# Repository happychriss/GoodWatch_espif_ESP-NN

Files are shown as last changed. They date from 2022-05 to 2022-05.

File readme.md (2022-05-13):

##### GoodWatch - a SuperSmart eInk ML Learning driven AlarmClock
## This version is using Arduino as a *Component* and allows ESP menuconfig adjustment

* using ML (Edge Impulse) Speech Recognition to set-up the Alarm
* using a guesture sensor for wake-up
* dimmable ePaper FrontLight for readability at night with a super soft dimm
* MP3 via SPIFF to play multiple wake-up sounds (moved now to SPIFF)
* ESP 32 Wemos Pro for programming
* power saving - runtime minimum 3 month on battery
* boot speed optimized with menuconfig
* PCB Board included
## Read more at: 
https://44-2.de/goodwatch-eink-alarm-clock-with-voice-recognition/

You will also find more information on the ESP32 programming using EdgeImpulse ML and transfer learning.

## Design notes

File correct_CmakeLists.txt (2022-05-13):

cmake_minimum_required(VERSION 3.16.0)
include($ENV{IDF_PATH}/tools/cmake/project.cmake)
list(APPEND EXTRA_COMPONENT_DIRS arduino)
project(GoodWatch_espif)

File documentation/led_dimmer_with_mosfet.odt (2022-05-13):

LED Dimming 21 V with MOSFET

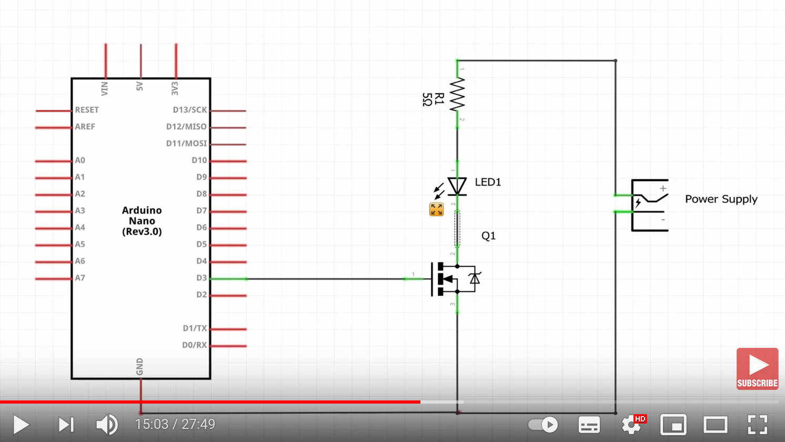
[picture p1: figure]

Type

IRF3708 (TO-220) http://s.click.aliexpress.com/e/_sUN3um

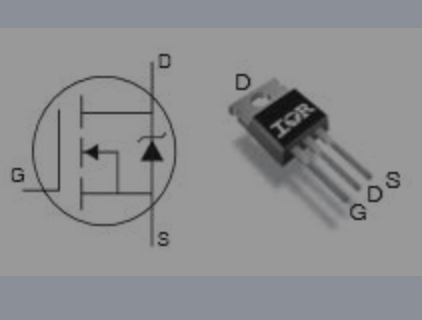
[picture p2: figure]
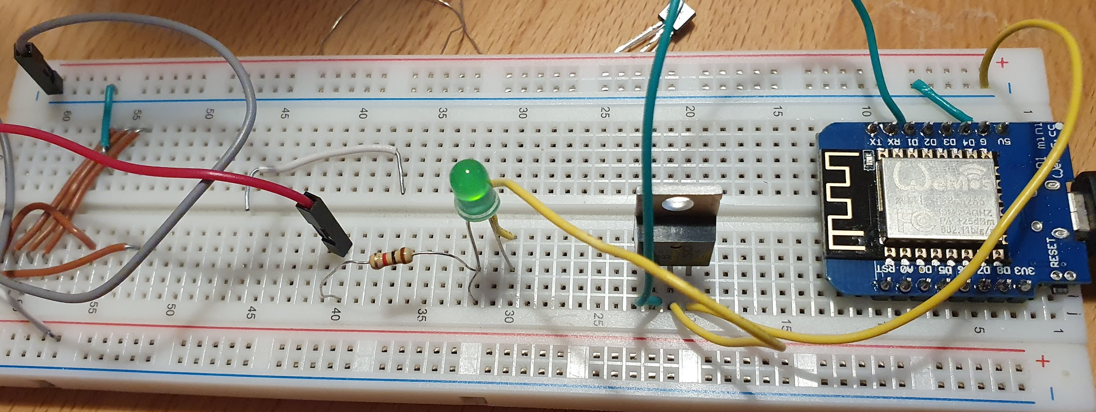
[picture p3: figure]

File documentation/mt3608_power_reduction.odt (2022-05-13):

Power Consumption of MT

https://hackaday.com/2019/01/27/reworking-mt3608-boost-converters-for-lower-idle-current-draw/

Idle poser consumption is above 1ma.

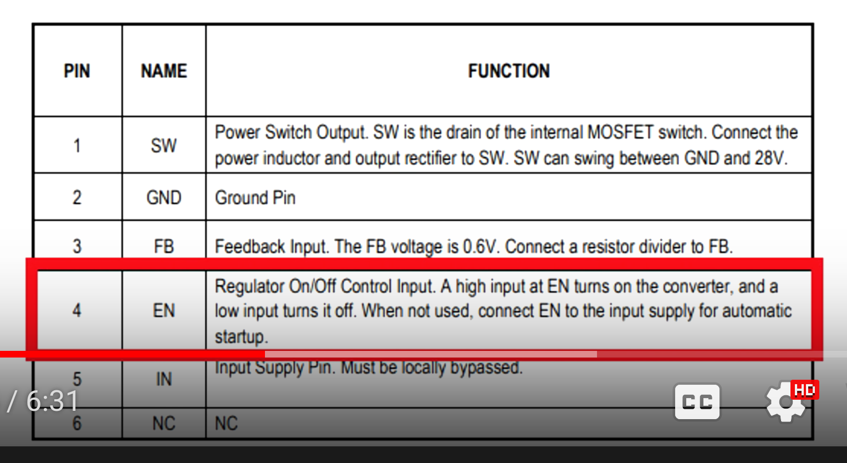
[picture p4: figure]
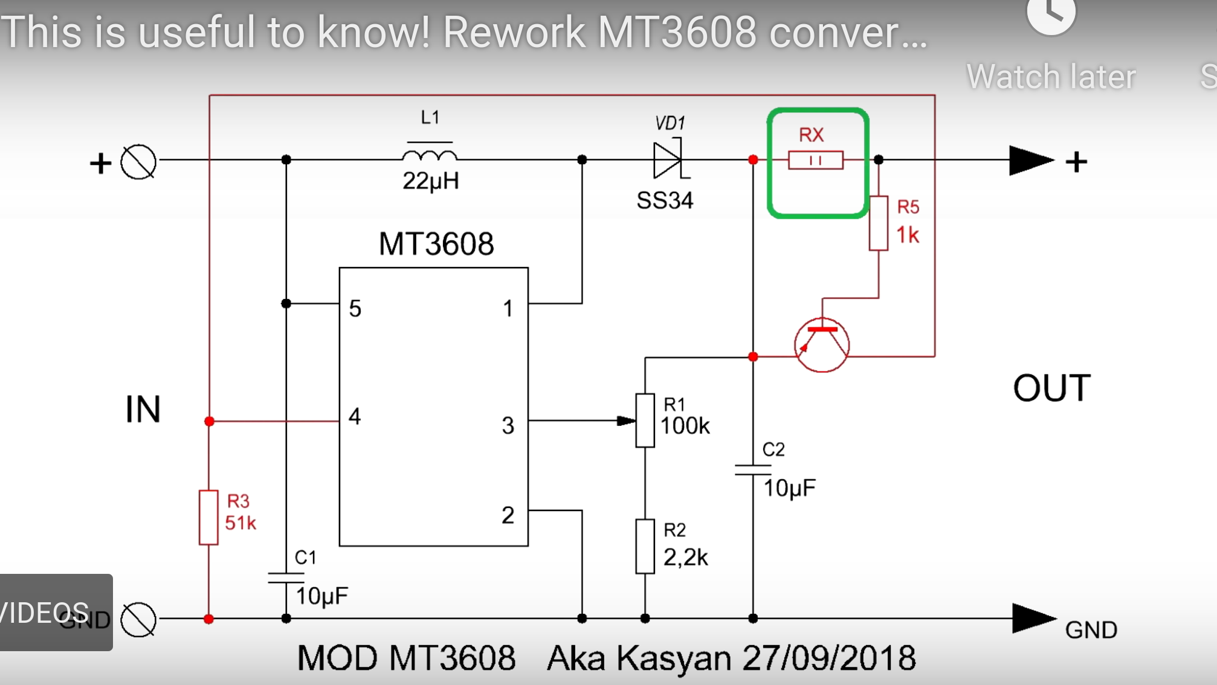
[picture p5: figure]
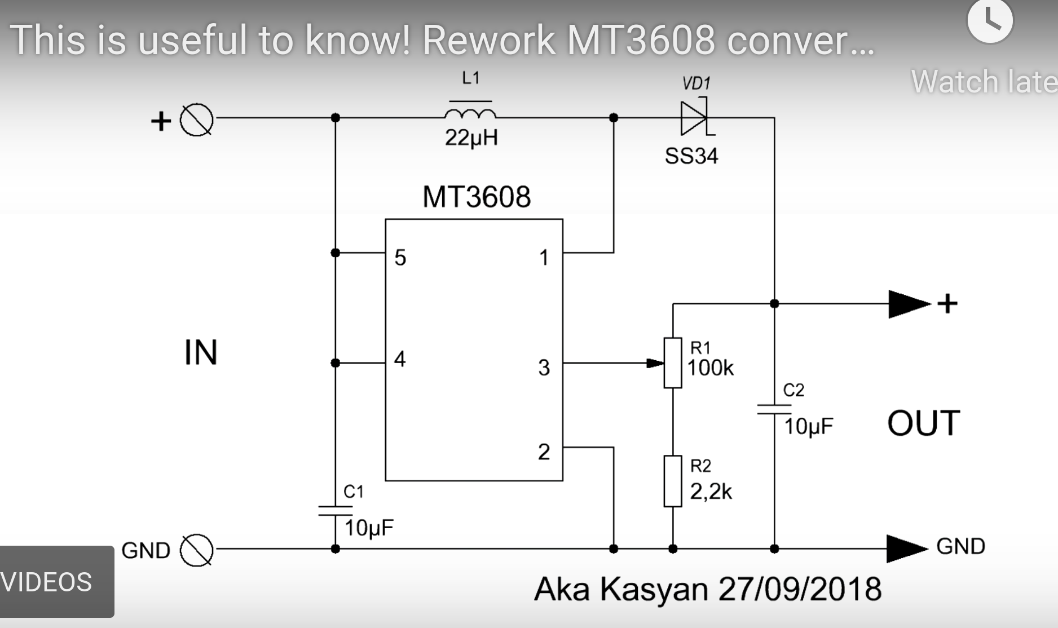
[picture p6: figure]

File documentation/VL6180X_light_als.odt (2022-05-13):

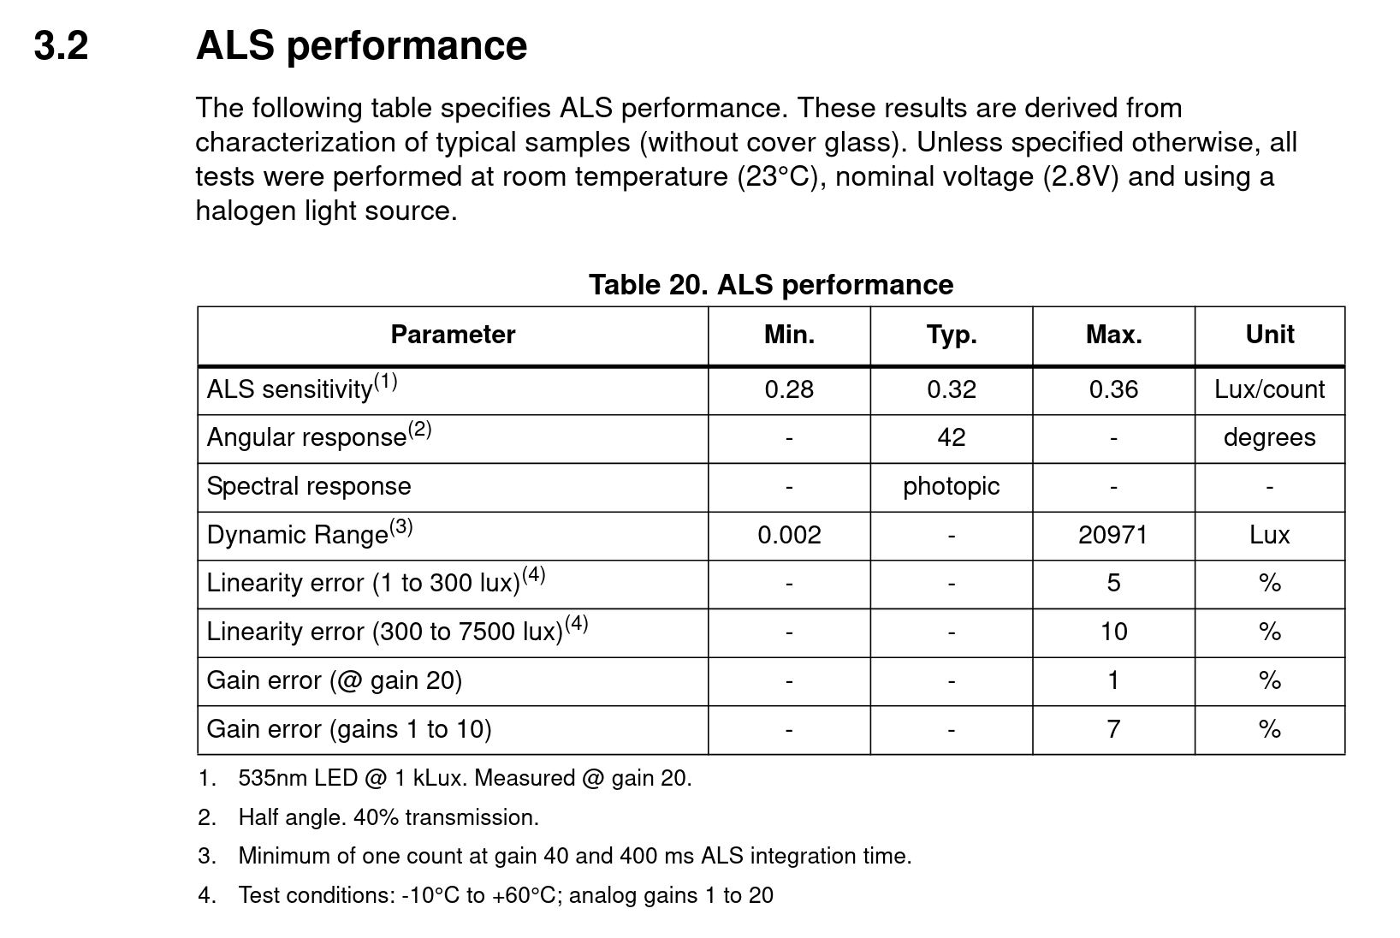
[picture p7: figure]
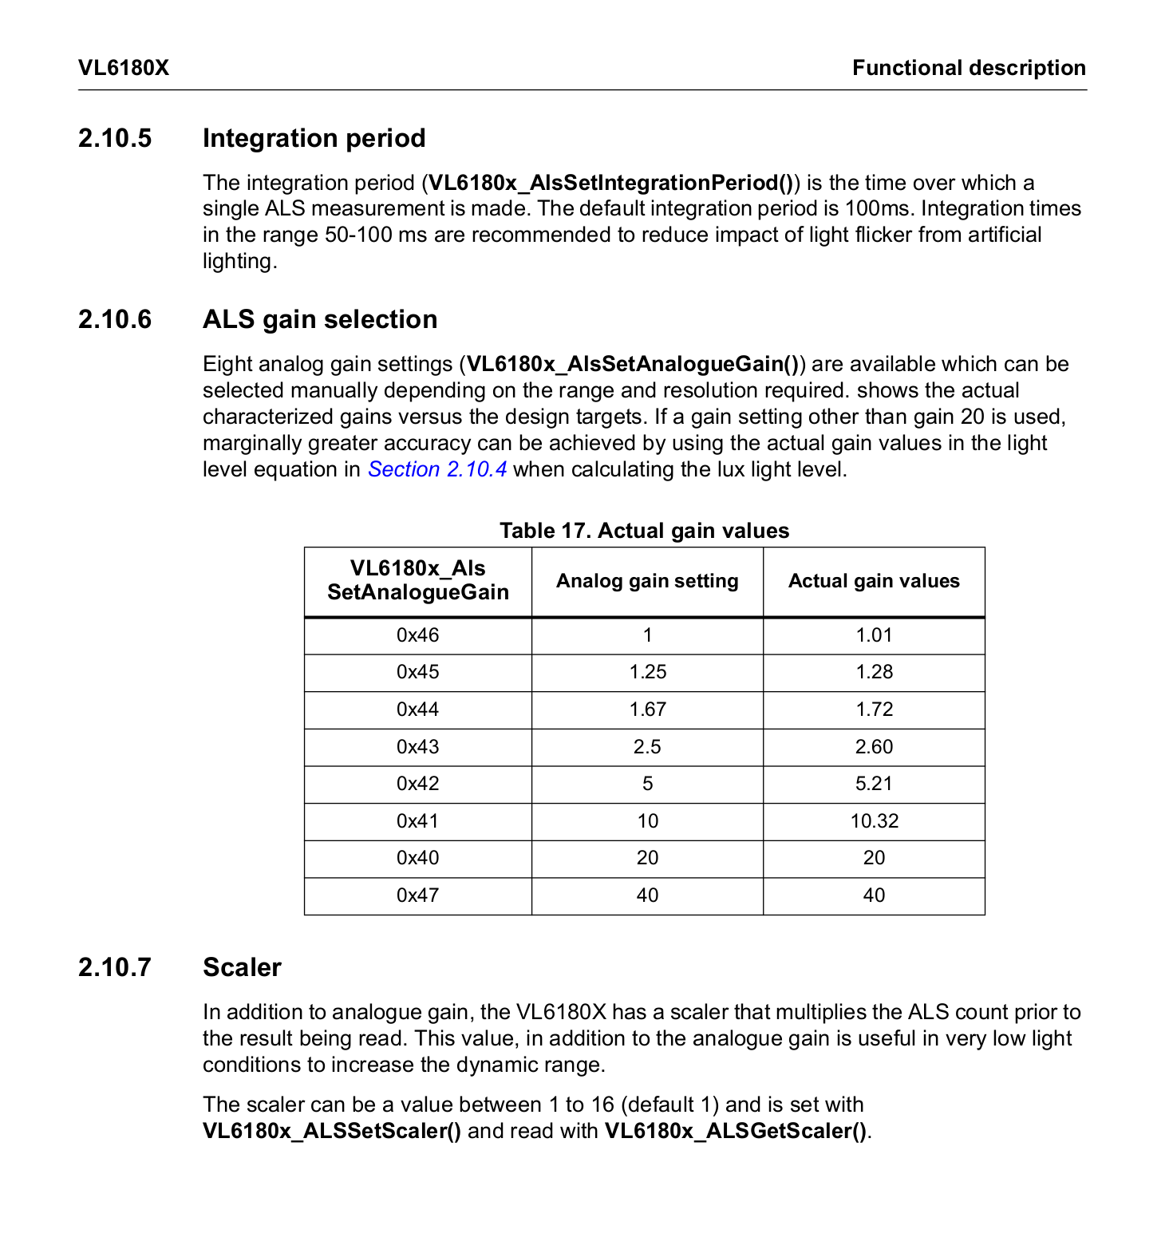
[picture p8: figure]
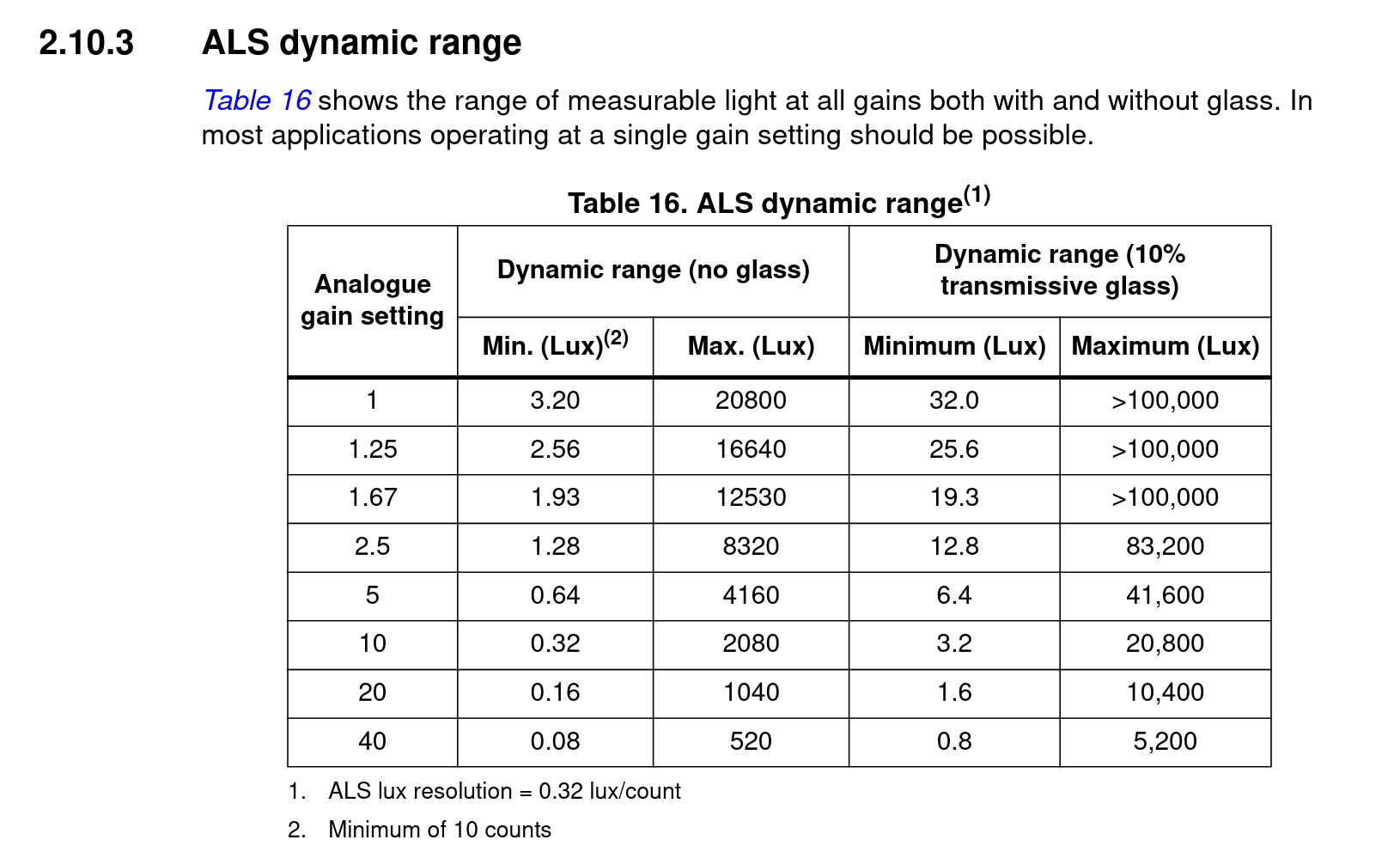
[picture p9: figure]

ALS

0.002 Lux

one count

ALS Analogue Gain: 0x47 = gain 40: SYSALS__ANALOGUE_GAIN = 7, address: 0x03F

ALS Integration Time: 400MS: SYSALS__INTEGRATION_PERIOD, Address: 0x040 = 0x18F (8.bit gesetzt)

ALS Scaler =16, FIRMWARE__RESULT_SCALER 0x7, address 0x120

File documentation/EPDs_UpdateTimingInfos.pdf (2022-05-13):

List of my e-paper displays and their update times and behavior

size | | | panel | controller | full update | | | | comment
inches | depth | pixel | | | time sec | time sec | to buffer | to screen
1,54 | b/w | 200x200 | GDEP015OC1 | IL3829 | 1,2 | 0,3 | √ | √
1,54 | 3-color | 200x200 | GDEW0154Z04 | IL0376F | 7,2 | 7,2 | - | - | controller has no window part addressing
2,13 | b/w | 128x250 | GDE0213B1 | IL3895 | 3,9 | 0,3 | √ | √ | phased out
2,13 | b/w | 128x250 | GDEH0213B72 | IL3897 | 1,7 | 0,2 | √ | √ | new replacement
2,13 | b/w | 128x250 | GDEH0213B73 | SSD1675B | 3,8 | 0,2 | √ | √ | newer replacement
2,13 | 3-color | 104x212 | GDEW0213Z16 | IL0373 | 15 | 15 | √ | √ | screen boarder flashes also
2.13 | b/w | 104x212 | GDEW0213I5F | IL0373 | 2,1 | 0,3 | √ | √ | flexible display
2,6 | b/w | 152x296 | GDEW026T0 | IL0373 | 1,6 | 1,3 | √ | √
2,7 | b/w | 176x264 | GDEW027W3 | IL91874 | 2 | 0,4 | √ | √ | with wavetable from new demo source
2,7 | 3-color | 176x264 | GDEW027C44 | IL91874 | 16 | 16 | √ | √ | leaves visible boarder of partial window
2,9 | b/w | 128x296 | GDEH029A1 | IL3820 | 1,6 | 0,42 | √ | √
2,9 | b/w | 128x296 | GDEW029T5 | IL0373 | 2,1 | 0,4 | √ | √
2,9 | 3-color | 128x296 | GDEW029Z10 | IL0373 | 15 | 15 | √ | √ | screen boarder flashes also
3,7 | b/w | 240x416 | GDEW0371W7 | IL0324 | 3 | 1,5 | √ | √ | charge balancing waveform table for differential update
4,2 | b/w | 400x300 | GDEW042T2 | IL0398 | 1,6 | 0,6 | √ | √ | new waveform table for differential update
4,2 | 3-color | 400x300 | GDEW042Z15 | IL0398 | 16 | 16 | √ | - | refresh to partial screen would modify the other half screen
5,83 | b/w | 600x448 | GDEW0583T7 | IL0371 | 15 | 15 | √ | - | controller provides no differential update
7,5 | b/w | 640x384 | GDEW075T8 | IL0371 | 4,3 | 4,3 | √ | - | controller provides no differential update
7,5 | b/w | 800x480 | GDEW075T7 | GD7965 | 4,2 | 1,6 | √ | √ | charge balancing waveform table for differential update
7,5 | 3-color | 640x384 | GDEW075Z09 | IL0371 | 32 | 32 | √ | - | controller provides no differential update
7,5 | 3-color | 800x480 | GDEW075Z08 | GD7965 | 17 | 17 | √ | (√) | 3-color allows no differential update

times are "busy active" times after refresh command sent to controller
"-" partial update to screen: whole screen updates (and flashes)
(√) partial update can be disabled in GxEPD2 (usePartialUpdate = false) for better image

4.2" b/w: new waveform table for differential update, compromise between ghosting and persistence

resolution | partial update

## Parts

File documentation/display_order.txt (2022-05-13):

1x8pin header right angle female single row socket connector 2.54mm pitch

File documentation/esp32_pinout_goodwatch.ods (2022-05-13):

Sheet: GoodWatch
GPIO | Input | Output |  | Notes
0 | pulled up |  | DC PIN | outputs PWM signal at boot
1 | TX Pin |  |  | debug output at boot
2 | OK |  | RESET | connected to on-board LED
3 | OK |  | RX Pin | HIGH at boot
4 | OK | OK | I2S-WS/LRCK | I2S Microphone
5 | OK | OK | SS/CS | outputs PWM signal at boot
6 | X | X |  | connected to the integrated SPI flash
7 | X | X |  | connected to the integrated SPI flash
8 | X | X |  | connected to the integrated SPI flash connected to the integrated SPI flash
9 | X | X |  | connected to the integrated SPI flash
10 | X | X |  | connected to the integrated SPI flash
11 | X | X |  | connected to the integrated SPI flash
12 | OK | OK | OK | POWER Controll (switch off other devices on sleep)
13 | OK | OK | OK
14 | OK | OK | OK | outputs PWM signal at boot
15 | OK | OK | BUSY | SPI – EPD, outputs PWM signal at boot, pill down – no debug
16 | OK | OK | OK | PSRAM?
17 | OK | OK | OK | PSRAM?
18 | OK | OK | SCK
19 | OK | OK | MISO/SDI
20 | OK | OK | not used
21 | OK | OK | SDA
22 | OK | OK | SCL
23 | OK | OK | MOSI/SDA
24
25 | OK | OK | DAC_1 | Sound Out
26 | OK | OK | DAC_2 | Light Out
27 | OK | OK | I2S BCK | I2S Microphone
28
29
30
31
32 | OK | OK | Interrup | Interrup Deeps Sleep
33 | OK | OK | Interrup | Interrup Deeps Sleep
34 | OK | input only | IS2-DATA | I2S Microphone
35 | OK | input only
36 | OK | input only | VP
37
38
39 | OK | input only | VN
https://diyprojects.io/esp32-gpio-pins-and-associated-functions-i-o-pwm-rtc-i2c-spi-adc-dac/

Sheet: LilyGo
GPIO | Function | Use in GoodWatch | Notes
0 | output only | EPD – DC | outputs PWM signal at boot, pulled up
1 | TX Pin – output only (debug at boot) |  | debug output at boot
2 | OK | EPD-RST
3 | RX Pin – Input Only – HIGH at boot |  | HIGH at boot
4 | SD Card Ship Select | n.a
5 | OK -outputs PWM signal at boot | EPD – Chips Select CS | outputs PWM signal at boot
12 | OK - boot fail if pulled high | I2S Speaker – Clock – BLCK | boot fail if pulled high
13 | OK – LED Buildin (inverse)
14 | OK | I2S Speaker – LeftRight – LRC | outputs PWM signal at boot
15 | OK | EPD Busy
16 | not available
17 | not available
18 | SPI – SCK | SD Card AND EPD
19 | SPI – MISO | SD Card
21 | OK – I2C SDA Default | I2S SDA Default (APDS Distrance Sensor)
22 | OK – I2C SCL Default | I2S SCL Default (APDS Distrance Sensor)
23 | SPI – MOSI for SD Card | SD Card AND EPD
25 | OK – Analog Out | I2S Microphone – Clock
26 | OK – Analog Out | I2S Speaker – LeftRight – LRC
27 | OK – Analog Out | PWM – Analog Out to controll EPD Dimming via MOSFET
32 | OK | I2S Microphone – DIN
33 | OK | I2S Microphone – LeftRight – LRC
34 | input only – Interrupt RCT | Wake-up ES32 from DeepSleep by APDS9960 Interrupt
35 | input only – Interrupt RCT | Battery Voltage, internal with voltage devider | https://www.youtube.com/watch?v=yZjpYmWVLh8&t=88s
36 | input only – Interrupt RCT - VP
39 | input only – Interrupt RCT -VN | Alarm Signal from RTC Watch
 | ome GPIO’s cannot be used freely, as they are already assigned to module peripherals or have special functions during booting:
 | GPIO0 pin is used as a bootstrapping pin, and should be low to enter UART download mode. Make sure it is not pulled low by a peripheral device during boot or the firmware will not start!
 | GPIO2 pin is used as a bootstrapping pin, and should be low to enter UART download mode. Make sure it is not pulled high by a peripheral device during boot or you will not be able to flash a firmware to the module!
 | GPIO06 through GPIO11 are reserved for the FLASH. You cannot use them at all!
 | GPIO12 is used as a bootstrapping pin to select output voltage of an internal regulator which powers the flash chip (VDD_SDIO). This pin has an internal pulldown so if left unconnected it will read low at reset (selecting default 3.3V operation). Make sure it is not pulled high by a peripheral device during boot or the module might not be able to start!
 | GPIO15 can be used to stop debug output on Serial during boot. If pulled low there will be no output on the Serial port during the boot process. This can be helpful in battery powered applications where you do not want to use the Serial port at all to reduce power consumption.
 | GPIO34-39 can only be set as input mode and do not have software pullup or pulldown functions
 | GPIO37 and 38 are not available on most modules
 | ESP32-PICO-D4:
 | GPIO16 and 17 are used for internal Flash (Readers input)
 | ESP32 WROVER:
 | GPIO16 and 17 are used for the PSRAM

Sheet: ESP Memore_RAM_FLASH
Name | type | Sub-type | offset | Size | KB | MB
nvx | data | nvs | 9000 | 5000 | 20 | 0.01953125
otadata | data | ota | E000 | 2000 | 8 | 0.0078125
app0 | app | Ota_0 | 10000 | 640000 | 6400 | 6.25
app0 | app | Ota_0 | 650000 | 640000 | 6400 | 6.25
spiffs | data | spiff | C90000 | 370000 | 3520 | 3.4375
 |  |  |  |  |  | 15.96484375
HARDWARE: ESP32 240MHz, 320KB RAM, 16MB Flash
RAM | [== ] 21.4% (used 70108 bytes from 327680 bytes)
Flash | [== ] 20.2% (used 1321445 bytes from 6553600 bytes) |  |  |  |  | ← Needed for program memore

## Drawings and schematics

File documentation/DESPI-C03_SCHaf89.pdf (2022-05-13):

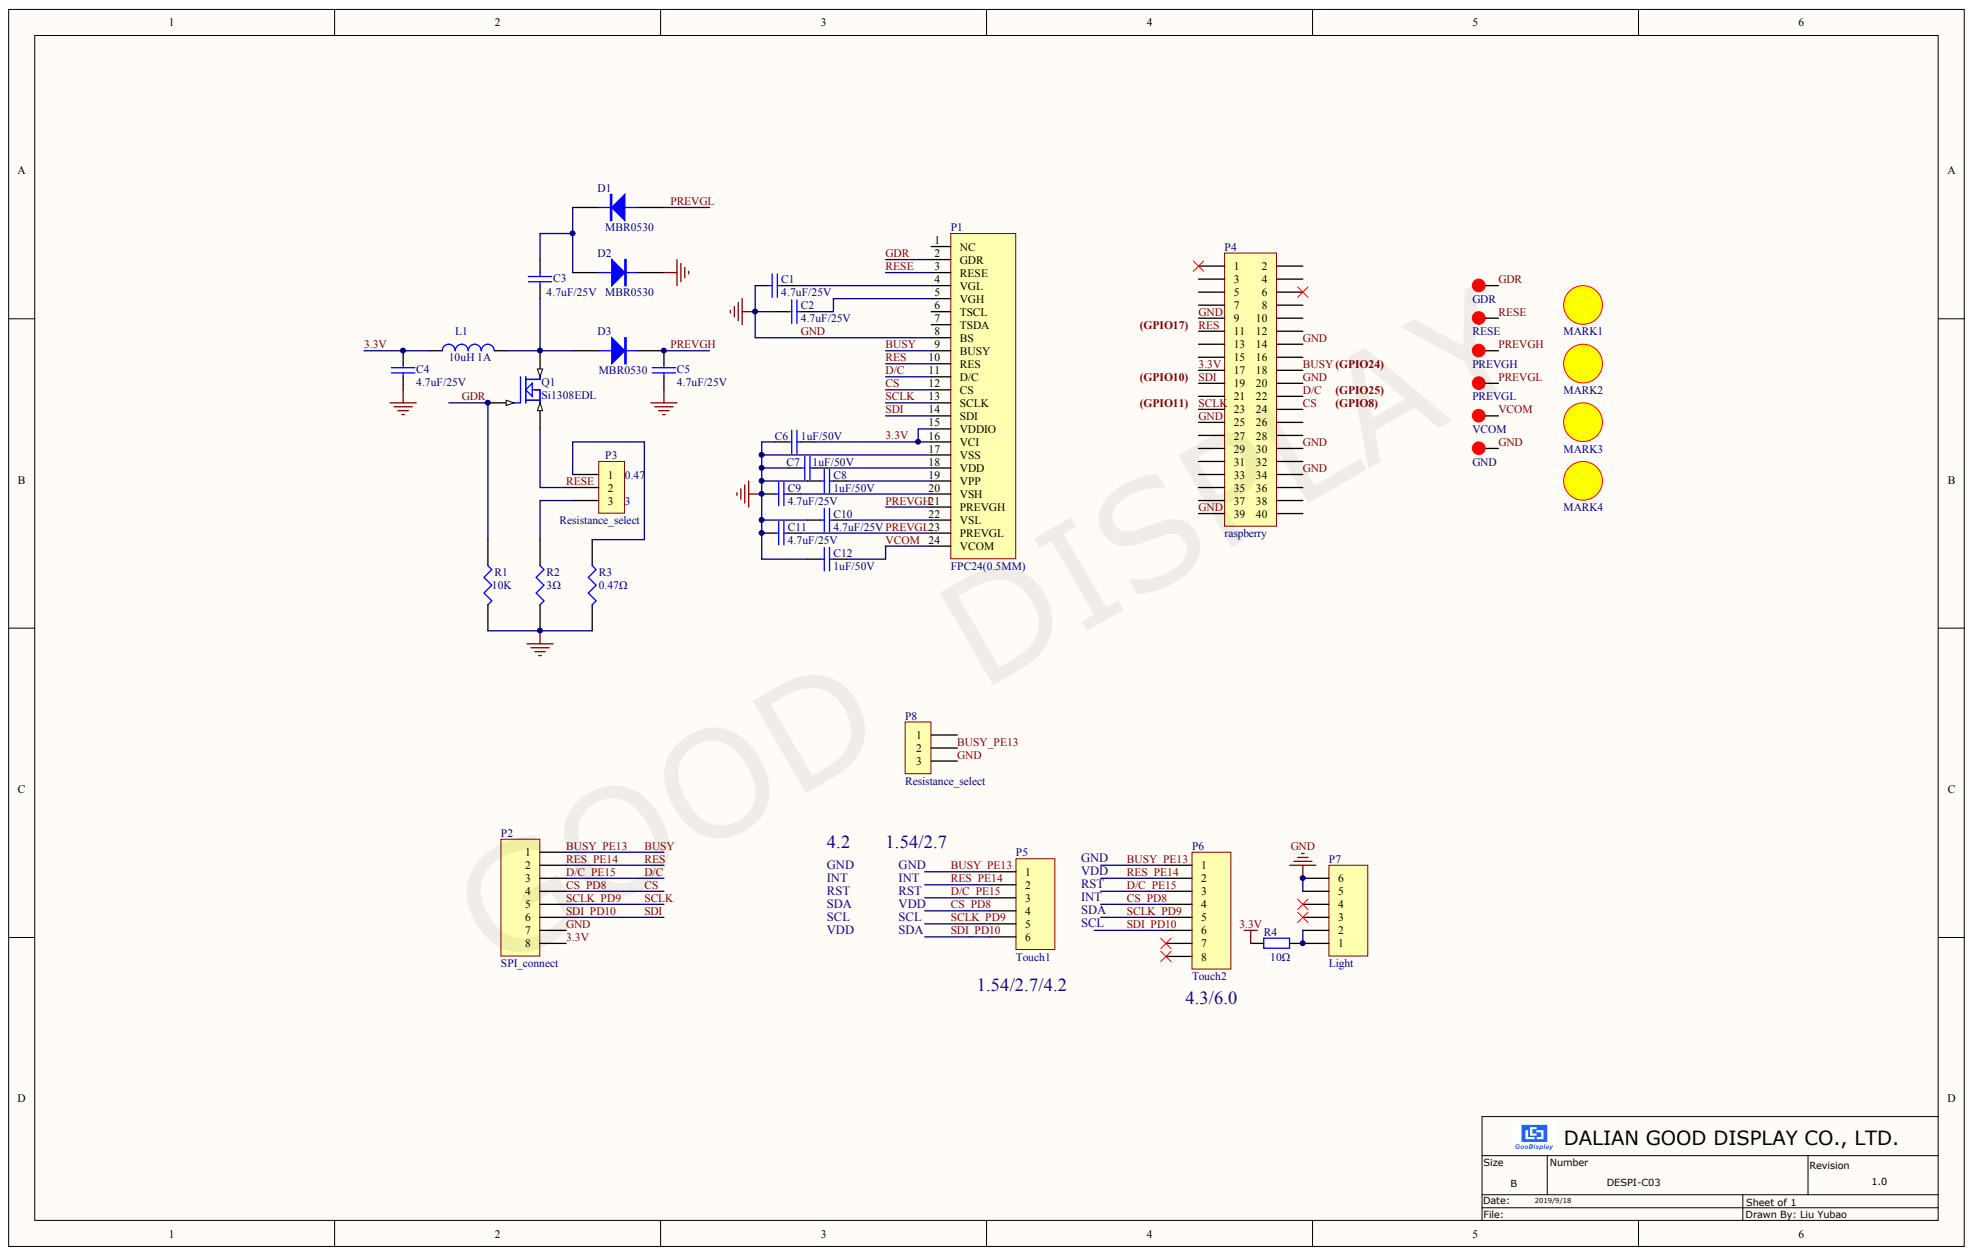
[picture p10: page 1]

C11 | | 4.7uF/25V PREVGL

VCOM

DALIAN GOOD DISPLAY CO., LTD.

Sheet of 1
Drawn By: Liu Yubao

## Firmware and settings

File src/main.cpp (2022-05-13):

#define ENABLE_GxEPD2_GFX 1
#define ARDUHAL_LOG_LEVEL 5

#include <Arduino.h>
#include "WiFi.h"
#include <time.h>
#include "support.h"
#include <global_hardware.h>
#include "driver/i2s.h"
#include "paint_alarm.h"
#include <my_RTClib.h>
#include <ArduinoOTA.h>
#include <SPIFFS.h>
#include "esp_spiffs.h"

// various


#include <lwip/apps/sntp.h>
#include "Audio.h"
#include "VL6180X.h"

// custom
#include <display_support.hpp>
#include <audio_support.hpp>
#include <rtc_support.h>

#include <wifi_support.h>
#include <support.h>
#include <paint_watch.h>
#include <esp_wifi.h>
#include <inference_sound.h>


// #define DATA_ACQUISITION -> check in file support.h
#undef DISABLE_EPD
#define DATA_ACQUISITION
#define DEBUG_DISPLAY 0 //115200


//********** Global Variables ***************************************************
// Wake Up Sensor
VL6180X distance_sensor;


// EPD Display
BitmapDisplay bitmaps(display);

// Inference Global Data
//inference_t *tmp_inf= (inference_t*) heap_caps_malloc(sizeof(inference_t), MALLOC_CAP_SPIRAM);#


// inference_t inference;
bool record_ready = false;
signed short *sampleBuffer;
bool debug_nn = false; // Set this to true to see e.g. features generated from the raw signal

QueueHandle_t m_i2sQueue;

// Audio playing
bool b_audio_end_of_mp3 = false;
bool b_audio_finished = true;

Audio audio;

RTC_DATA_ATTR bool b_watch_refreshed = false;
// RTC_DATA_ATTR int min_sim=1;
RTC_DS3231 rtc_watch;
RtcData rtcData;


esp_sleep_wakeup_cause_t wakeup_reason;

bool b_pir_wave = false;


#define CLOCK_INTERRUPT_PIN 39

void IRAM_ATTR Ext_INT1_ISR() {
    b_pir_wave = true;// Do Something ...

}


void setup() {

    Serial.begin(115200);
    DPL("****** SETUP ***************");

    // Setup pin input and output
    pinMode(LED_BUILTIN, OUTPUT);
    pinMode(PIR_INT, INPUT);
    pinMode(DISPLAY_CONTROL, OUTPUT);
    pinMode(DISPLAY_AND_SOUND_POWER, OUTPUT);
    pinMode(BATTERY_VOLTAGE, INPUT);
    pinMode(RTC_INT, INPUT_PULLUP);
    digitalWrite(DISPLAY_AND_SOUND_POWER, LOW);
    digitalWrite(DISPLAY_CONTROL, LOW);

    // Keep the alarm times https://github.com/espressif/esp-idf/blob/bcbef9a8db54d2deef83402f6e4403ccf298803a/examples/storage/nvs_rw_blob/main/nvs_blob_example_main.c
    esp_err_t err = nvs_flash_init();
    if (err == ESP_ERR_NVS_NO_FREE_PAGES || err == ESP_ERR_NVS_NEW_VERSION_FOUND) {
        // NVS partition was truncated and needs to be erased Retry nvs_flash_init
        ESP_ERROR_CHECK(nvs_flash_erase());
        err = nvs_flash_init();
        DPL("!!!!!!!!!!!! NVS ERROR !!!!!!!!!!!!!!!!");
    }
    ESP_ERROR_CHECK(err);
    i2s_init();


    if (false) {
        //        pinMode(GPIO_NUM_34, INPUT_PULLUP);
        delay(2500);
        PlayWakeupSong();
    }






}

/* MAIN LOOP *********************************************************************************************/

void loop() {
    DPL("****** Main Loop ***********");

    wakeup_reason = print_wakeup_reason();

    if (!rtc_watch.begin()) {
        DPL("Couldn't find RTC!");
        abort();
    }
    DateTime now = rtc_watch.now();
    DP("RTC Time now:");
    DPL(DateTimeString(now));

//    I2C_Scanner();

    int adc = analogRead(BATTERY_VOLTAGE);
    double BatteryVoltage;
    BatteryVoltage = (adc * 7.445) / 4096;
    DP("Battery V: ");
    DPL(BatteryVoltage);

    /*
        // **********************************************************************************************
        // Normal Boot **********************************************************************************
        // **********************************************************************************************
    */

    if (wakeup_reason == ESP_SLEEP_WAKEUP_UNDEFINED) {
        DPL("!!!! ****** Boot ******  !!!!");
        // stop oscillating signals at SQW Pin
        // otherwise setAlarm1 will fail
        SetupWifi_SNTP();

        rtc_watch.writeSqwPinMode(DS3231_OFF);
        rtc_watch.disable32K();
        rtc_watch.clearAlarm(ALARM1_5_MIN);
        rtc_watch.clearAlarm(ALARM2_ALARM);
        rtcSetRTCFromInternet();
        DPF("RTC Init with Temperature: %f\n", rtc_watch.getTemperature()); // in Celsius degree

        display.init(DEBUG_DISPLAY, true);
        PaintWatch(display, false, false);

    } else {
        // Check RTC  Clock ****************************************************************
        DPL("!!!! ****** Wakeup ****** !!!!");
        if (rtc_watch.lostPower()) {
            DPL("!!!!!RTC Watch lost power - Reset from Internet");
            SetupWifi_SNTP();
            rtcSetRTCFromInternet();
        } else {
            DPL("!!!!! Set ESP time from RTC");
            rtsSetEspTime(rtc_watch.now());
        }

    }

/*
    // **********************************************************************************************
    // Alarm Clock Wakeup ***************************************************************************
    // **********************************************************************************************
*/

    DPL("Checking other wakeup reasons....");
    if (wakeup_reason == ESP_SLEEP_WAKEUP_EXT1) {
        DPL("!!!! RTC Alarm Clock Wakeup");
        /* 5 min wakeup  ***************************************************************************/
        if (rtc_watch.alarmFired(ALARM1_5_MIN)) {
            DPL("*** Alarm1 Fired: Alarm for 5min refresh");
            DPL("!!! RTC Wakeup after 5min");
            rtc_watch.clearAlarm(ALARM1_5_MIN);
            rtc_watch.disableAlarm(ALARM1_5_MIN);
            rtsSetEspTime(rtc_watch.now());
            display.init(DEBUG_DISPLAY, false);
            PaintWatch(display, true, false);
        }

        /* Alarm wakeup  ***************************************************************************/
        if (rtc_watch.alarmFired(ALARM2_ALARM)) {
            DPL("*** Alarm2 Fired: ALARM for Wakeup");
            rtc_watch.clearAlarm(ALARM2_ALARM);
            rtc_watch.disableAlarm(ALARM2_ALARM);
            rtcData.getRTCData();

            if (UpdateRTCWithNextAlarms()) {
                rtcData.writeRTCData();
                SetNextAlarm(true);
                dim_light_up_down_esp32(true);
                digitalWrite(DISPLAY_AND_SOUND_POWER, HIGH);
                attachInterrupt(PIR_INT, Ext_INT1_ISR, HIGH);

                PlayWakeupSong();
                dim_light_up_down_esp32(false);
                detachInterrupt(PIR_INT);

                while (digitalRead(PIR_INT) == true) {
                    delay(100);
                }

                display.init(DEBUG_DISPLAY, true);
                PaintWatch(display, false, false);
            } else {
                DPL("Alarm was fired by RTC, no active Alarm found on RTC-Data - dont do anything");
            }

        };

    }

/*     // **********************************************************************************************
       // PIR Sensor Wakeup*****************************************************************************
       // ***********************************************************************************************/

    if (wakeup_reason == ESP_SLEEP_WAKEUP_EXT0) {

        DPL("!!!! PIR Sensor Wakeup !!!! ");
        DistanceSensorSetup();
        uint16_t avg_proximity_data = distance_sensor.readRangeSingleMillimeters();
        DPF("*** Distance[mm]: %i\n", avg_proximity_data);
        dim_light_up_down_esp32(true);

/*      // **********************************************************************************************
        // VERY CLOSE - Data Acuisition and OTA Update **************************************************
        // ***********************************************************************************************/

        if (avg_proximity_data < 30) { //hand is very close
            DPL("Proximity-Check: Very close: Config Goodwatch");
            SetupWifi_SNTP();
            display.init(DEBUG_DISPLAY);
            ConfigGoodWatch(display);
            display.clearScreen();
            PaintWatch(display, false, false);
        } else if (avg_proximity_data < 70) { //hand a bit away

/*          // **********************************************************************************************
            // Medium Close - Show Alarm Screen ********** **************************************************
            // ***********************************************************************************************/

            DPL("Proximity-Check: A bit away: Program Alarm");
            display.init(DEBUG_DISPLAY, true);
            ProgramAlarm(display);
            PaintWatch(display, false, false);
        } else {
            DPL("Proximity-Check: No Hand: Quick Time");
            display.init(DEBUG_DISPLAY, false);
            PaintQuickTime(display, false);
        }

        // Give the PIR time to go down, before going to sleep
        while (digitalRead(PIR_INT) == true) {
            delay(100);
        }

    }


/*    // **********************************************************************************************
    // DEEP SLEEP ***********************************************************************************
    // ***********************************************************************************************/


    DPL("Prepare deep sleep");

    dim_light_up_down_esp32(false);
    while (max_light_level!=0 or !b_audio_finished) {
        DPL("WAIT for Light or Sound to finish");
        delay(10);
    }; //wait for the light to go off
    digitalWrite(DISPLAY_AND_SOUND_POWER, LOW);

//    esp_sleep_enable_timer_wakeup(sleep_sec * 1000 * 1000);
#define WAKUEP_INTERVAL 5
    DateTime dt = now_datetime();
    int next_wake_up_min = (((dt.minute()) / WAKUEP_INTERVAL) * WAKUEP_INTERVAL) + WAKUEP_INTERVAL;
    if (next_wake_up_min == 60) next_wake_up_min = 0;
    DateTime alarm(0, 0, 0, 0, next_wake_up_min, 0);
    DPF("Next wakeup min: %i\n", next_wake_up_min);
    rtc_watch.setAlarm1(alarm, DS3231_A1_Minute);

    //ext0 allows you to wake up the ESP32 using one single GPIO pin;
    //ext1 allows you to wake up the ESP32 using several GPIO pins.
    // Alarm from RTC
    esp_sleep_enable_ext1_wakeup(0x8000000000, ESP_EXT1_WAKEUP_ALL_LOW); //1 = High, 0 = Low

    // Alarm from PIR
    esp_sleep_enable_ext0_wakeup(GPIO_NUM_34, HIGH); //1 = High, 0 = Low
    //delay(1000);
    display.powerOff();
/*  Not sure if needed
    Wire.end(); // shutdown/power off I2C hardware,
    pinMode(SDA,INPUT); // needed because Wire.end() enables pullups, power Saving
    pinMode(SCL,INPUT);
*/
    esp_wifi_stop();
    esp_deep_sleep_start();
//    esp_light_sleep_start();

}

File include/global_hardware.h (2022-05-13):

//
// Created by development on 29.06.21.
//

#ifndef GLOBAL_H
#define GLOBAL_H



// display size
#define MAX_X 400
#define MAX_Y 300

#define INF_ERROR (-1)

// Distance Measurement APDS9960 via *I2C* and GPIO 21=SDA and 22=SCL
#define PIR_INT   34  // Needs to be an interrupt pin

#define RTC_INT 39 // VN Pin

// Display Light
#define DISPLAY_CONTROL 27 //dims the light
#define DISPLAY_AND_SOUND_POWER 13// enables the  MT3608 (power for display and the MAX98357A (I2S Sound, SD to ground)

//SD Card (Pins are not used, set as default) using SPI together with EPD
#define SD_CS          4
#define SPI_MOSI      23    // SD Card
#define SPI_MISO      19
#define SPI_SCK       18

//I2S Interface for Loudspeaker
#define I2S_NUM_1_BCLK 12
#define I2S_NUM_1_LRC 14
#define I2S_NUM_1_DOUT 26

//I2S Interface for Microphone
#define I2S_NUM_2_BCLK 25
#define I2S_NUM_2_LRC 33
#define I2S_NUM_2_DIN 32

#define BATTERY_VOLTAGE 35

// EPD Pins - GxEPD2_display_selection_new_style.h using SPI
// EPD Pins****
// CS=5, DC=0, RST=2,BUSY=15;
// SPI: SCK=18, SDI=MISO=23
// BUSY -> 15, RST -> 2, DC -> 0, CS -> 5, CLK -> SCK(18), DIN -> MOSI(23), GND -> GND, 3.3V -> 3.3V

#define EPD_CS 5 // Chip Select -
#define EPD_DC 0
#define EPD_RST 2
#define EPD_BUSY 15


#endif //GLOBAL_H

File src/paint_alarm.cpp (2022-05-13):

//
// Created by development on 13.08.21.
//
#include "Arduino.h"
#include "paint_alarm.h"
#include <Fonts/FreeSans12pt7b.h>
#include "inference_sound.h"
#include "driver/i2s.h"
#include <my_RTClib.h>
#include "global_display.h"
#include "paint_support.h"
#include <rtc_support.h>
#include <paint_support.h>
#include <ArduinoOTA.h>
#include "Audio.h"
#include "audio_support.h"
#include <FS.h>
#include <SPIFFS.h>



extern Audio audio;

// days start Sunday
struct str_watch_config wc[ALARM_NUMBERS_DISPLAY] = {
        {{1, 1, 1, 1, 1, 1, 1}, single,    3 * PT12_HEIGHT,                  "Einmal-1"}, // every day of the week
        {{1, 1, 1, 1, 1, 1, 1}, single,    4 * PT12_HEIGHT,                  "Einmal-2"}, // every day of the week
        {{0, 1, 1, 1, 1, 1, 0}, repeating, 5 * PT12_HEIGHT + PT12_BREAK,     "MO-FR-1"}, // MO-FR
        {{0, 1, 1, 1, 1, 1, 0}, repeating, 6 * PT12_HEIGHT + PT12_BREAK,     "MO-FR-2"},  // MO-FR
        {{1, 0, 0, 0, 0, 0, 1}, repeating,  7 * PT12_HEIGHT + 2 * PT12_BREAK, "WE"}, // Bike MO-FR

};


inference_t inference;

extern RTC_DS3231 rtc_watch;
extern RtcData rtcData;


void TestAlarmWrite() {
    // schedule an alarm 10 seconds in the future
    DateTime wakeup=     rtc_watch.now() + TimeSpan(60);
    DP("Wakeup:"); DPL( DateTimeString(wakeup));
    if(!rtc_watch.setAlarm2(
            wakeup,
            DS3231_A2_Date // this mode triggers the alarm when the seconds match. See Doxygen for other options
    )) {
        Serial.println("Error, alarm wasn't set!");
    }else {
        Serial.println("Alarm will happen in 60 seconds!");
    }
    DateTime now=rtc_watch.now();
    DateTime rtc_alarm = {};
    rtc_watch.getAlarm2(&rtc_alarm, now);
}

// This functions checks for an alarm, if it should be set for the next day depending on the alarm type

DateTime DetermineAlarmDay(int alarm_type_index, int hour, int min) {
    DateTime tmp_now = now_datetime();
    DP("TimeBase: ");DPL(DateTimeString(now_datetime()));

    DateTime input_time = DateTime(tmp_now.year(), tmp_now.month(), tmp_now.day(), hour, min);

    DPL("** Correct Time **");
    DPF("Input Time[%i]: ", alarm_type_index);
    DPL(DateTimeString(input_time));

    DateTime res = input_time;

    int curr_day = tmp_now.dayOfTheWeek();
    int new_day = curr_day;

    int offset_day=0;
    if (input_time <= tmp_now) {
        new_day = curr_day + 1;
        offset_day=1;
        DPL("Offset Day added");
    }
    if (new_day > 6) new_day = 0;

    for (int c = 0; c < 7; c++) {
        DPF("i: %i c: %i, next_day: %i, watch_config: %i\n", alarm_type_index, c, new_day, wc[alarm_type_index].days[new_day]);
        if (wc[alarm_type_index].days[new_day] == 1) {
            res = input_time + TimeSpan((c+offset_day) * 24 * 60 * 60);
            break;
        }
        new_day++;
        if (new_day > 6) new_day = 0;
    }


    DP("Result Time: ");
    DPL(DateTimeString(res));
    return res;
}

int SortTimes(void const *a, void const *b) {
    const struct strct_alarm *ad = (struct strct_alarm *) a;
    const struct strct_alarm *bd = (struct strct_alarm *) b;
    return (int) (ad->time.secondstime() - bd->time.secondstime());
}

bool UpdateRTCWithNextAlarms() {

    bool b_valid_alarm_found=false;

    DateTime tmp_now = now_datetime();
    DP("TimeBase UpdateRTC: ");DPL(DateTimeString(tmp_now));

    for (int i = 0; i < ALARM_NUMBERS_DISPLAY; i++) {
        if (rtcData.d.alarms[i].active) {
            TimeSpan diff = (tmp_now - rtcData.d.alarms[i].time).seconds();
            DPF("Checking [%i]: %s: - Seconds:%i", i, rtcData.str_short(i).c_str(), diff.seconds());

            if (diff.seconds() < 15 && diff.seconds() >= 0 && diff.hours() == 0 && diff.minutes() == 0) {

                b_valid_alarm_found=true;

                if (wc[i].type == single) {
                    DPL("Single Alarm - Update: deactivated");
                    rtcData.d.alarms[i].active = false;
                }

                if (wc[i].type == repeating) {
                    rtcData.d.alarms[i].time = DetermineAlarmDay(i, rtcData.d.alarms[i].time.hour(), rtcData.d.alarms[i].time.minute());
                    DPF("Repeating Alarm - Updated: %s\n", rtcData.str_long(i).c_str());

                }

            } else
                DPL("- not relevant");
        }

    }

    return b_valid_alarm_found;
}

int SetNextAlarm(bool b_write_to_rtc) {
    int i;
    DateTime tmp_now = now_datetime();
    DP("TimeBase SetNextAlarm: ");DPL(DateTimeString(tmp_now));

    DPL("Input:");
    for (int i = 0; i < ALARM_NUMBERS_DISPLAY; i++) {
        DPF("RTC Alarm[%i]: %s- State: %i\n", i, rtcData.str_long(i).c_str(), rtcData.d.alarms[i].active);
    }
    qsort(rtcData.d.alarms, ALARM_NUMBERS_DISPLAY, sizeof(strct_alarm), SortTimes);
    DPL("PostSort:");
    for (int i = 0; i < ALARM_NUMBERS_DISPLAY; i++) {
        DPF("RTC Alarm[%i]: %s - State: %i\n", i, rtcData.str_long(i).c_str(), rtcData.d.alarms[i].active);
    }

    // Find first relevant alarm
    int next_alarm = -1;

    for (i = 0; i < ALARM_NUMBERS_DISPLAY; i++) {
        if ((rtcData.d.alarms[i].active) && (rtcData.d.alarms[i].time > tmp_now)) {
            next_alarm = i;
            break;
        }
    }

    if (b_write_to_rtc) {
        if (next_alarm >= 0) {
            DPF("Next active alarm [%i]: %s\n", next_alarm, rtcData.str_short(next_alarm).c_str());
            DateTime alarm = rtcData.d.alarms[next_alarm].time;
            DPF("************ Setting Alarm[%i]: ", next_alarm);
            DPL(DateTimeString(alarm));

            bool b_set_alarm = false;
            DP("Write-Alarm: ");DPL(DateTimeString(alarm));
            rtc_watch.clearAlarm(ALARM2_ALARM);
            for (int ac=0;ac<15;ac++) {
                DP("Try: "); DPL(ac);
                if (rtc_watch.setAlarm2(alarm, DS3231_A2_Date)) {
                    b_set_alarm = true;
                    break;
                }
                delay(500);
            }
            DPL("Done");

            if (!b_set_alarm) {
                DPL("!!!!!!!! ERROR SETTING ALARM!!!!!!!!!!!!!!!!!!!!!!!!!!!!!!");
                DPL(DateTimeString(alarm));
                next_alarm = -1;
            }
        } else {
            DPL("************ No active alarm");
            // not really working: https://www.avrfreaks.net/forum/how-check-current-alarm-status-or-deactivate-alarm-ds3231
            rtc_watch.clearAlarm(ALARM2_ALARM);
            rtc_watch.disableAlarm(ALARM2_ALARM);

        }
    }
    return next_alarm;

}


DateTime updateAlarmTime(const char *str_alarm, int alarm_typ_index) {
    DateTime tmp_time;
    int alarm_hour = ((int) str_alarm[0] - '0') * 10 + (int) str_alarm[1] - '0';
    int alarm_min = ((int) str_alarm[3] - '0') * 10 + (int) str_alarm[4] - '0';
    DPF("Wake up on: %i:%i\n", alarm_hour, alarm_min);

    return DetermineAlarmDay(alarm_typ_index, alarm_hour, alarm_min);

}

void PaintAlarmScreen(GxEPD2_GFX &d, const char title[]);
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
